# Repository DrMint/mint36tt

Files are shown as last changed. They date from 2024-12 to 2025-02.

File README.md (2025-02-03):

# Mint36tt (provisional name)

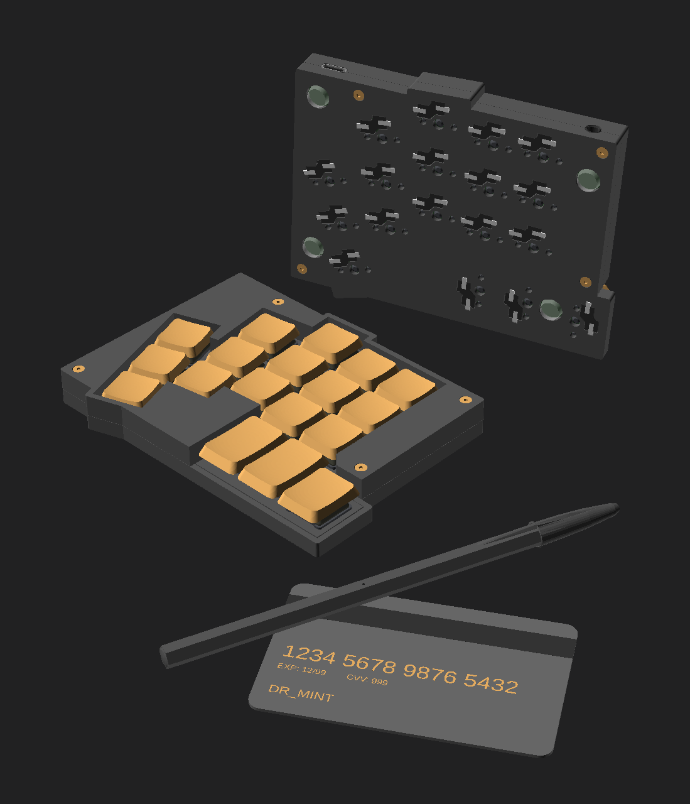
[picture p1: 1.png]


## Design goals

1. Ergonomic
   - Split
   - Reduced number of keys
   - Reduced key spacing
   - Splay
2. On-the-go

   - Low profile
   - Silent
   - Small footprint
   - key protection
   - Light
   - USB-C

3. Sourceable
   - Open source hardware
   - 3D printable (FDM)
   - Common components
   - Hot swappable board and switches
   - Reasonably cheap

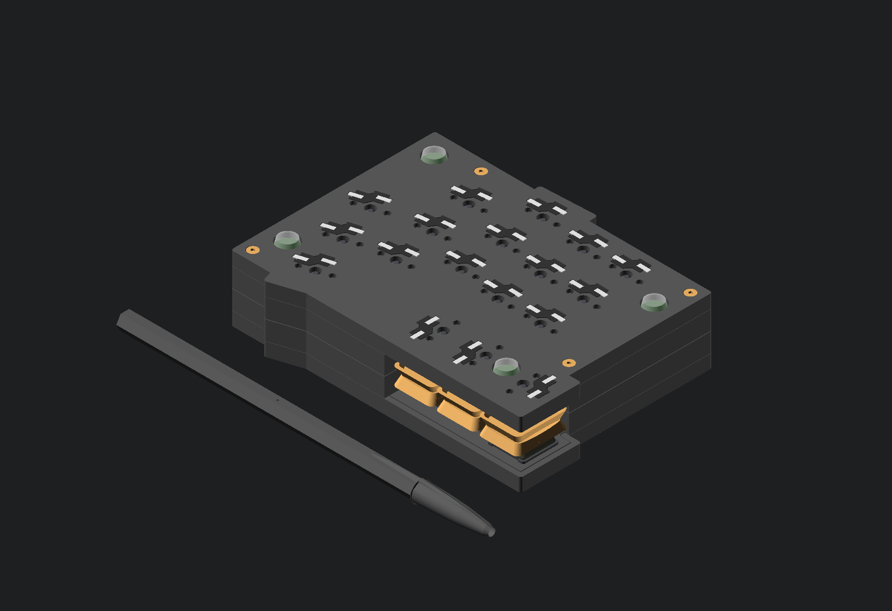
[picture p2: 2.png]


_The two halves combines together using magnets to transform into its own carry case. This prevent damage to the keys during transport and protect the keyboard from dust._

Physical sizes for one half:

**Width**: 118.5mm  
**Height**: 90.5mm  
**Thickness**: 14.8mm
**Weight**: 110g (wired version)

## Switches

Kailh Choc switches are the thinnest at 11mm (ref. https://www.reddit.com/r/MechanicalKeyboards/comments/165c11v/the_biggest_issue_with_lowprofile_switches_they/).

There are thinner switches such as the Kailh Notebook X (6.5mm) or the Cherry MX Ultra low-profile (3.5mm). But these are more expensive and don't have much variety.

Choosen switches: **[Kailh Choc Ambient Silent](https://lowprokb.ca/products/ambients-silent-choc-switches)**

## Key caps

Chocs standard keycaps are 16.5mm × 17.5mm. I decided to go with 16.5mm × 16.5mm CBX keycaps from Chosfox, which results in a 17.5mm spacing (a ~15% area reduction compared to MX's 19mm spacing).

It's possible to buy [15mm keycaps](https://3dkeycap.com/products/choc-colored-keycap-set) for a 16mm spacing (~30% area reduction). That would be the smallest possible spacing when paired with Chocs as 15mm is already the size of the switches.

It's also possible to reduce the gap beween keys. The standard is 1mm, but it could possibly be reduced to 0.5mm if the switches have little to no wobble and the tolerances on other parts are top notch.

Choosen caps: **[CFX caps](https://chosfox.com/collections/choc-keycaps)**

## Microcontroller

Choosen microcontroller: **[Seeed Studio XIAO RP2040](https://www.seeedstudio.com/XIAO-RP2040-v1-0-p-5026.html)** or **[Seeed Studio XIAO nRF52840](https://www.seeedstudio.com/Seeed-XIAO-BLE-nRF52840-p-5201.html)** for wireless.

## Shopping list

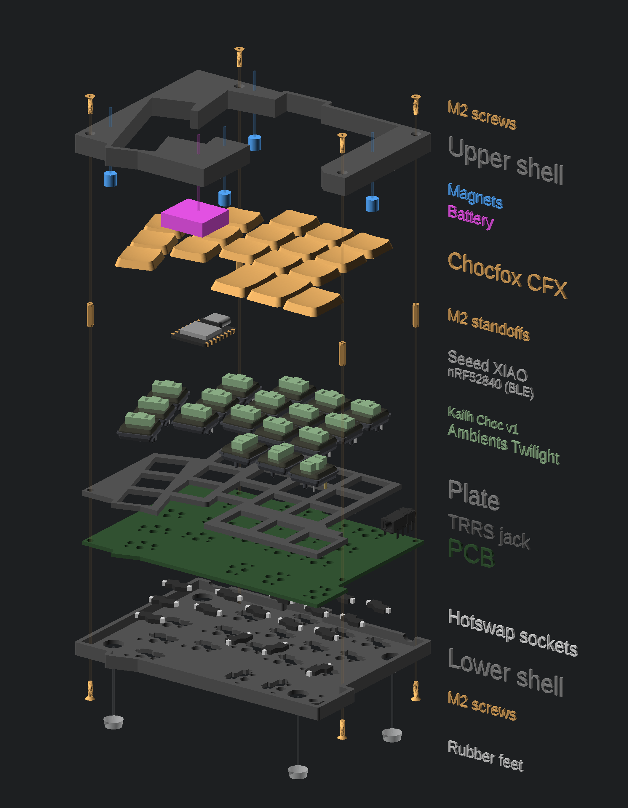
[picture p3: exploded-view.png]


### Common for either version

- Left and right PCBs
- 4 × 7 pin headers
- 36 × 1N4148W SOD123 diodes
- 36 × Chocfox CFX caps, including:
  - 30 × 1U Chocfox CFX caps
  - 2 × 1.25U Chocfox CFX caps
  - 4 × 1.5U Chocfox CFX caps
- 36 × Kailh Choc switches
- 36 × Kailh Choc Hot Swap Sockets
- 1 × USB-C cable

### Specific for the wireless version

- 2 × Seeed Studio XIAO nRF52840
- 2 × 601818 LiPo 3.7V 170mAh (18mm × 20mm × 6mm)
- 2 × MSK12C02 on/off slide switch

### Specific for the wired version

- 2 × Seeed Studio XIAO RP2040
- 1 × TRRS cable
- 2 × TRRS jacks PCB mount (MJ-4PP-9 or PJ320A)

### With the case (recommended):

- Left and right upper cases
- Left and right lower cases
- Left and right plates (optional)
- 8 × N52 neodymium magnet (cylinder-shaped, Ø 5mm × 5mm) (recommended)
- 20 × M2 countersunk screws (Ø 2mm × 5mm)
- 10 × M2 standoffs (Ø 2mm × 9mm)

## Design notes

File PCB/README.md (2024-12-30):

# Mint36tt

## Generate PCB file

```sh
npm i
npm start
```

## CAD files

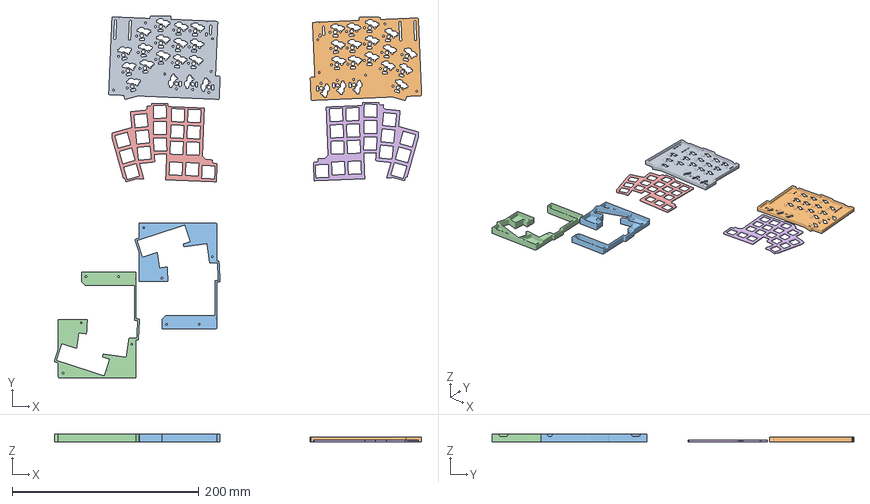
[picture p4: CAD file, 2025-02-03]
Case/mint36tt.3mf
393.8 x 388.0 x 8.90 mm
lower_shell_left.stl
lower_shell_right.stl
upper_shell_right.stl
upper_shell_left.stl
plate_right.stl
plate_left.stl

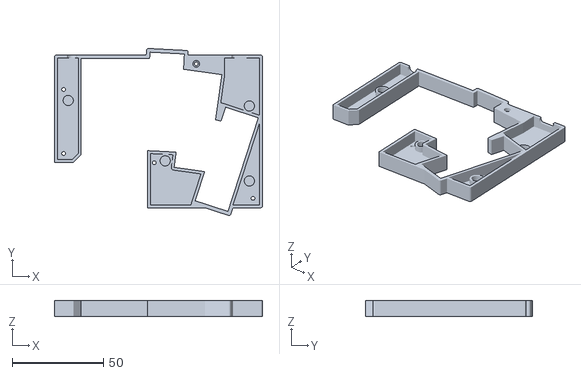
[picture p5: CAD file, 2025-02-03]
Case/STLs/Left/upper_shell_left.stl
113.7 x 91.3 x 8.90

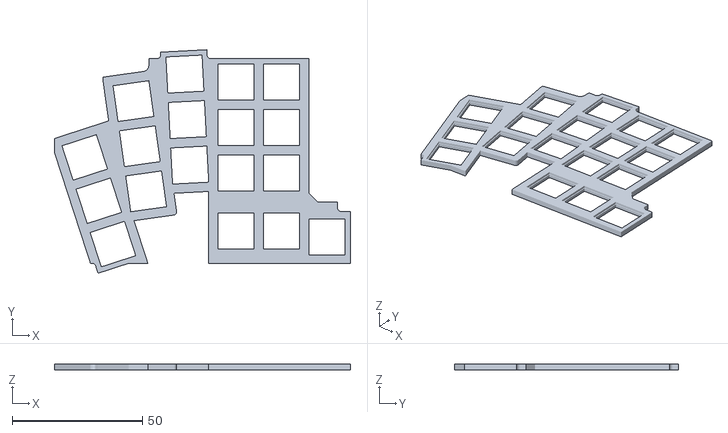
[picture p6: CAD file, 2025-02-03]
Case/STLs/Right/plate_right.stl
113.7 x 85.9 x 2.20

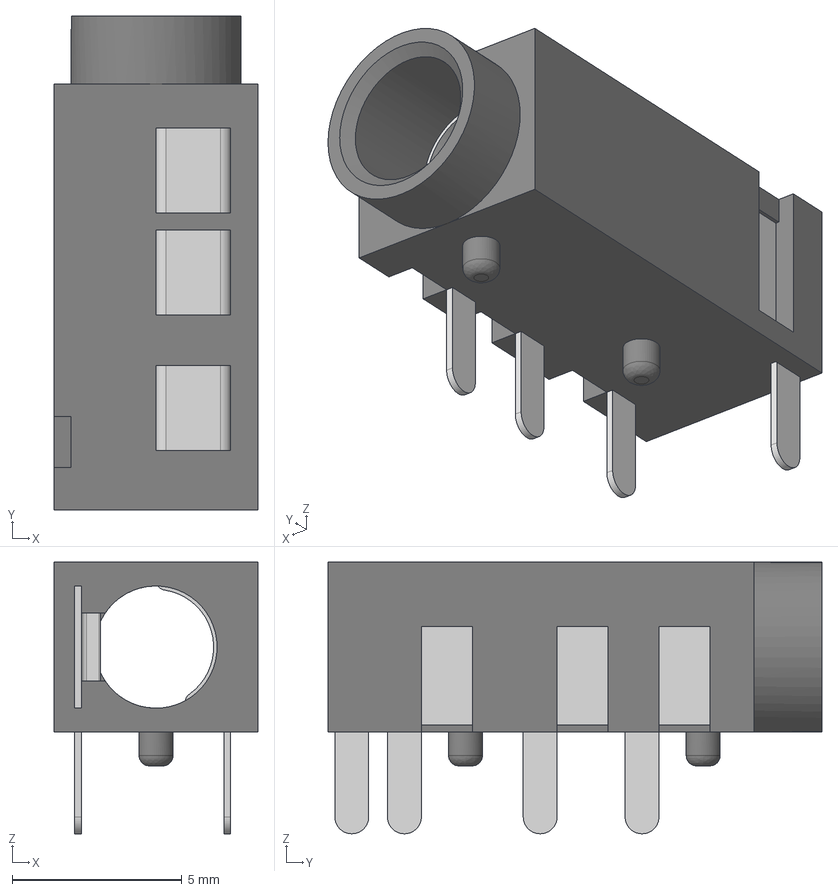
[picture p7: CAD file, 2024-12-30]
PCB/3d-models/PJ320A.step
6.00 x 14.6 x 8.00 mm

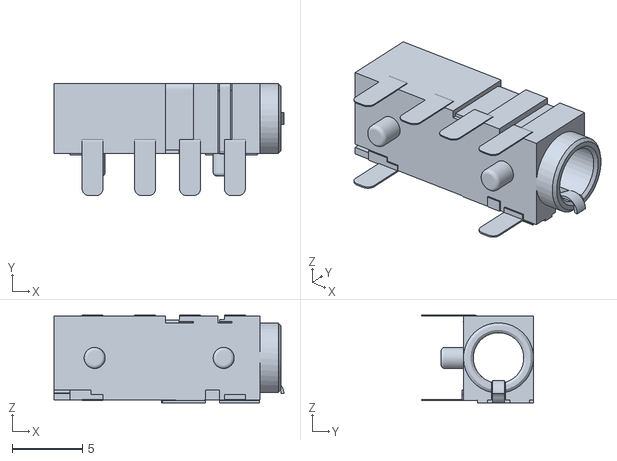
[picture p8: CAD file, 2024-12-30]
Case/components/ttrs-jack.stl
16.4 x 8.00 x 6.25

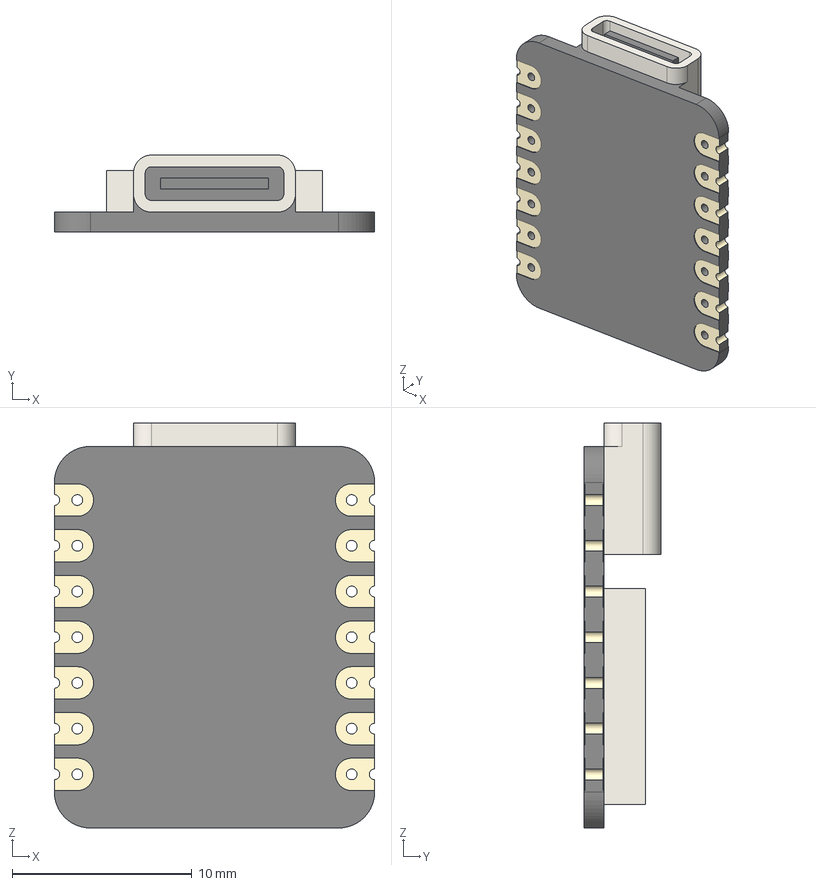
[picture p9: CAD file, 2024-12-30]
PCB/3d-models/XIAO-nRF52840.step
17.8 x 4.27 x 22.5 mm

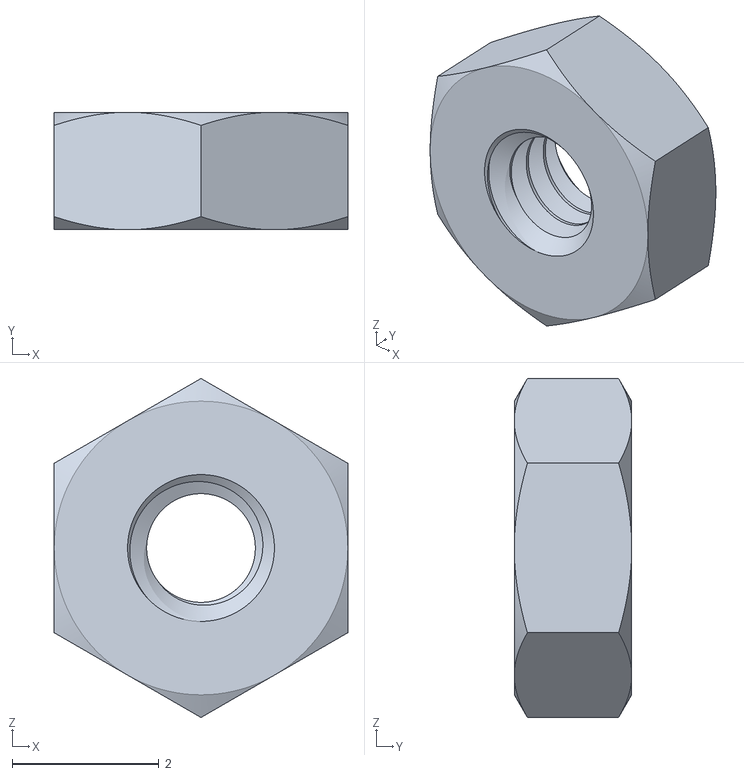
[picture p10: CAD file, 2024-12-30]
Case/components/m2-standoff.stl
4.00 x 1.60 x 4.62

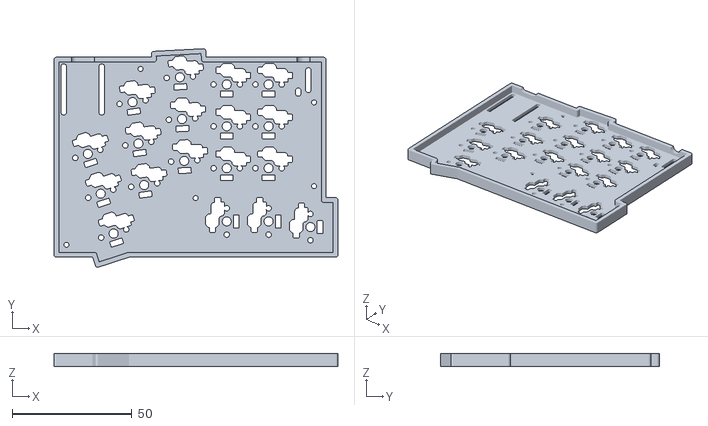
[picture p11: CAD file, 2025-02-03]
Case/STLs/Left/lower_shell_left.stl
118.7 x 91.3 x 5.60

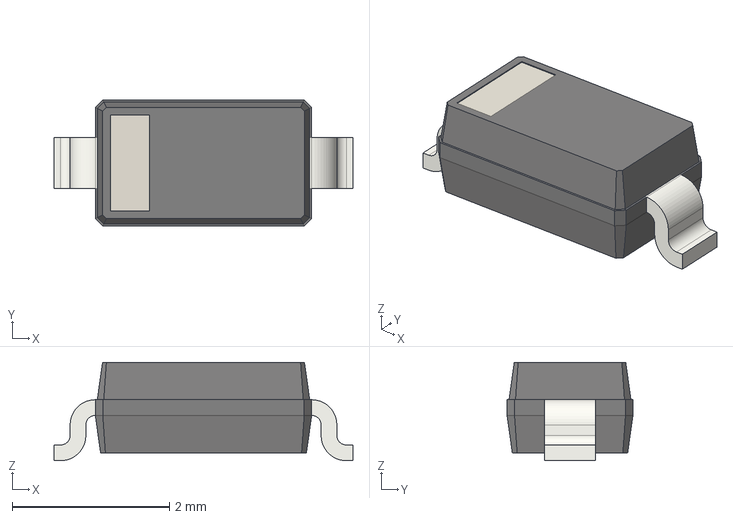
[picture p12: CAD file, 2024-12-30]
PCB/3d-models/SOD-123.step
3.80 x 1.60 x 1.25 mm

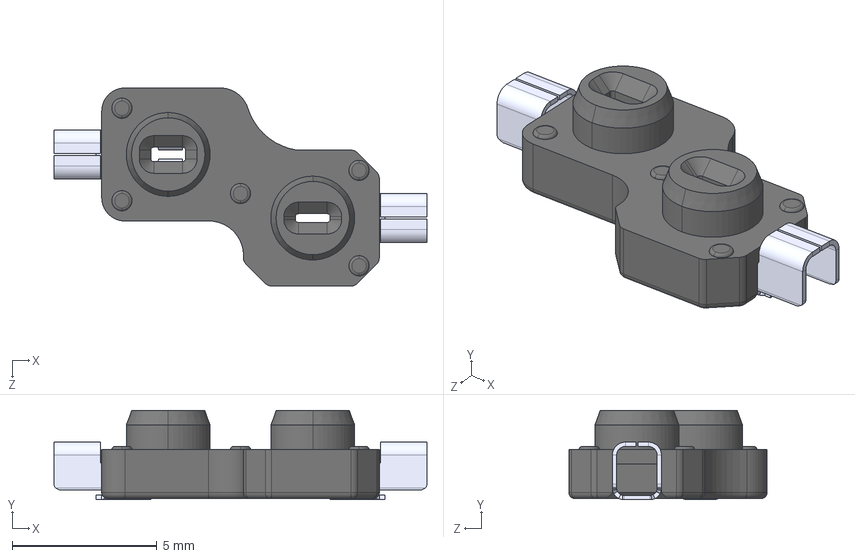
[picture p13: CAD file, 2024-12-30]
PCB/3d-models/PG1350-hotswap.step
12.9 x 3.09 x 6.85 mm
pin x 2
socket

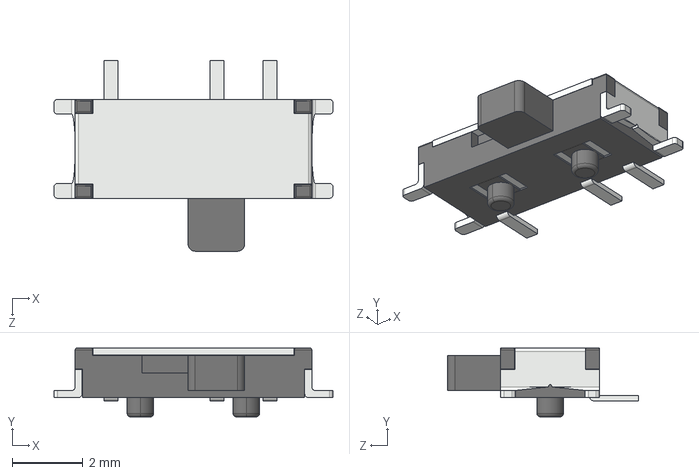
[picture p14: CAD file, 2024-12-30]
PCB/3d-models/MSK12C02.step
7.90 x 1.95 x 5.39 mm

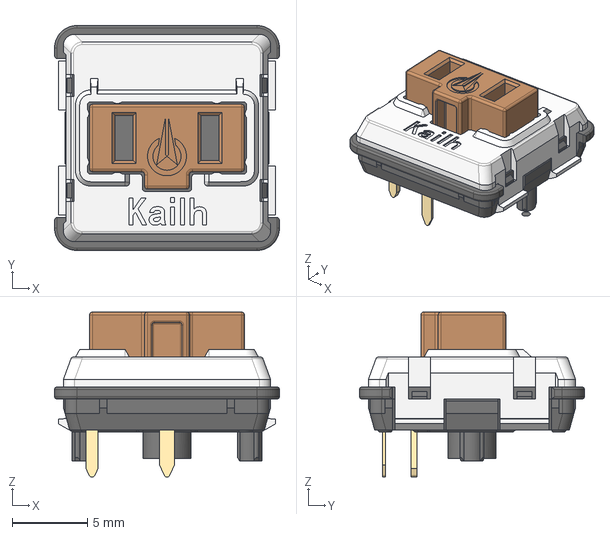
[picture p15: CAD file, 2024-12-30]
PCB/3d-models/PG1350-switch.step
15.0 x 15.0 x 11.0 mm

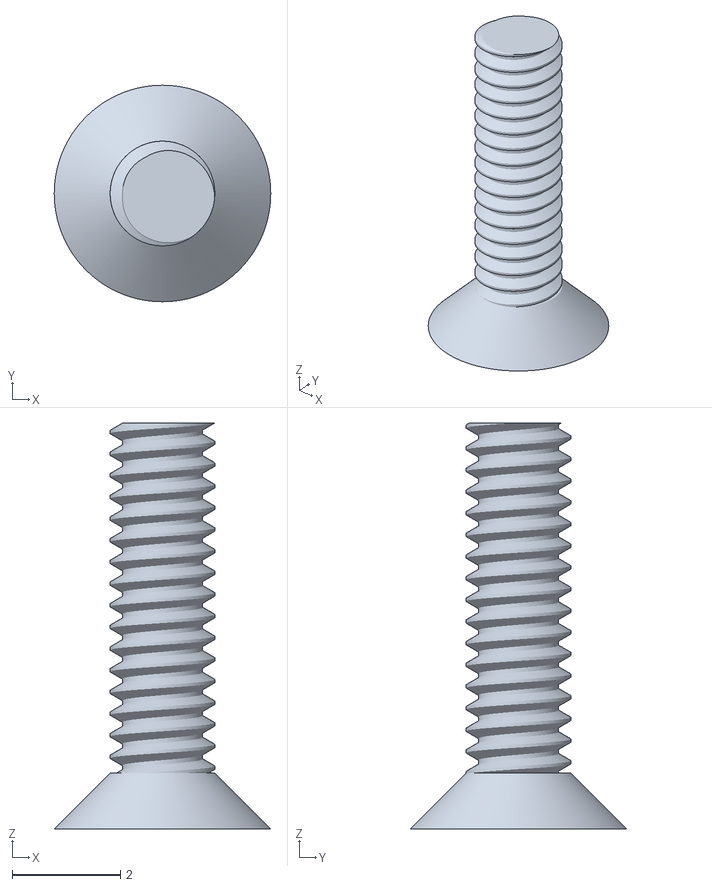
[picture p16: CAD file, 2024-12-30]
Case/components/m2-screw-6mm.stl
4.00 x 4.00 x 7.50

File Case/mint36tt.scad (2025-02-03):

include <./components/kailh-choc-v1.scad>
include <./components/cfx-caps.scad>

// include <./common.scad>

// Width: 117.5mm
// Height: 91mm
// Thickness: 14.7mm (14.0mm without the rubber feets)


/* [3D printing] */
kerf = 0.1;

/* [Keycaps & switches] */
Enable_switches = true;
Enable_caps = true;
Keycap_color = "#ffffffaa";
Thumb_cluster_color = "#eeeeee";

/* [Shell] */
Wall_thickness = 2.0;
Shell_size = [111.7, 81.575];
Shell_position = [-71.2, -53.675];
Shell_color = "#555555";

/* [Upper shell] */
Enable_upper_shell = true;
Upper_shell_thickness = 2.5;
Upper_shell_height = 8.9;
Enable_magnets = true;
Upper_shell_magnet_thickness = 0.5;
Magnet_height = 5.0;
Magnet_diameter = 5.0;

/* [Lower shell] */
Enable_lower_shell = true;
Lower_shell_thickness = 1.8;

/* [Plate] */
Enable_plate = true;
Plate_thumb_size = [116.7, 22.875];
Plate_thickness = 2.2;

/* [Screws] */
Enable_screws = true;
Screw_hole_radius = 1;
Screw_hole_distance = 1.5;
Countersink_height = 1.2;
Countersink_diameter = 3.5;
Screw_spacer_radius = 3.1/2;

/* [Microcontroller] */
Enable_microcontroller = true;
Micro_size = [17.8, 21, 1.26];
Micro_size_with_USB = 22.7;
Micro_position = [-67.6, 6.4, -1];

/* [Battery] */
Enable_battery = true;
Battery_size = [18, 20, 6];
Battery_position = [-20.1, -42.95];

/* [PCB] */
Enable_PCB = true;
PCB_thickness = 1.6;
Enable_sockets = true;
Enable_TTRS = true;
TTRS_position = [28.8, 12.5, -5.2];

/* [Debug] */
Debug_splay = 32.0; // [0:1:32]
Debug_text_distance = 70;
Debug_text_shift = 15;
Enable_debug_text = true;


module keys(withoutThumb=false, cutout=false, batteryCutout=false) {
    if (cutout) translate([-ku, ku]) capSize(16.8, 16.8) children();
    translate([0, ku]) capSize(16.8, 16.8) capColor(Keycap_color) children();
    translate([0, 0]) capSize(16.8, 16.8) capColor(Keycap_color) children();
    translate([0, -ku]) capSize(16.8, 16.8) capColor(Keycap_color) children();
    
    translate([ku, ku]) capSize(16.8, 16.8) capColor(Keycap_color) children();
    translate([ku, 0]) capSize(16.8, 16.8) capColor(Keycap_color) children();
    translate([ku, -ku]) capSize(16.8, 16.8) capColor(Keycap_color) children();
    
    rotate(3) translate([-18.5, 4]) {
        if (cutout) translate([ku, 0]) capSize(16.8, 16.8) children();
        translate([0, ku]) capSize(16.8, 16.8) capColor(Keycap_color) children();
        translate([0, 0]) capSize(16.8, 16.8) capColor(Keycap_color) children();
        translate([0, -ku]) capSize(16.8, 16.8) capColor(Keycap_color) children();
    }
    
    rotate(8) translate([-37.58, -2]) {
        if (cutout) translate([ku, ku]) capSize(16.8, 16.8) children();
        if (cutout) translate([ku, 0]) capSize(16.8, 16.8) children();
        if (batteryCutout) translate([1.25, ku * 2]) rotate(-8) capSize(16.8, 16.8) children();
        translate([0, ku]) capSize(16.8, 16.8) capColor(Keycap_color) children();
        translate([0, 0]) capSize(16.8, 16.8) capColor(Keycap_color) children();
        translate([0, -ku]) capSize(16.8, 16.8) capColor(Keycap_color) children();
    }
    
    rotate(18) translate([-58.79, -10.5]) {
        if (cutout) translate([ku, ku / 2]) rotate(-5) capSize(16.8, 16.8) children();
        if (cutout) translate([ku / 2, 0]) capSize(16.8, 16.8) children();
        if (batteryCutout) translate([0, -ku * 2]) capSize(16.8, 16.8) children();
        if (batteryCutout) translate([ku, ku]) capSize(16.8, 16.8) children();
        translate([0, ku]) capSize(16.8, 16.8) capColor(Keycap_color) children();
        translate([0, 0]) capSize(16.8, 16.8) capColor(Keycap_color) children();
        translate([0, -ku]) capSize(16.8, 16.8) capColor(Keycap_color) children();
    }
    
    if (!withoutThumb) rotate(0) translate([ku, -35.65 - gap]) {
        if (cutout) rotate(45) translate([5, 0]) capSize(16.8, 16.8) children();
        translate([ku, -5.475]) capSize(21.35, 16.8) rotate(90) capColor(Thumb_cluster_color) children();
        translate([0, -3.1]) capSize(26.1, 16.8) rotate(90) capColor(Thumb_cluster_color) children();
        translate([-ku, -3.1]) capSize(26.1, 16.8) rotate(90) capColor(Thumb_cluster_color) children();
    }
}

module screwPositions() {
    translate([36.5, 10]) children();
    translate([36.5, -25]) children();
    translate([-67, -49.5]) children();
    translate([-36, 24]) children();
    translate([-13, -30]) children();
}

module magnetPositions() {
    translate([34, 4]) children();
    translate([-19, -29]) children();
    translate([-65, 1]) children();
    translate([-65, -40]) children();
}

module rubberFeetPositions() {
    translate([26, -40]) children();
    translate([33.5, 13]) children();
    translate([-63.5, 20]) children();
    translate([-63.5, -40]) children();
}

half();
*translate([120, 0, 0]) half(flip=true);


/* [Hidden] */
zshift = $preview ? 0.01 : 0;
base_size = 16.5;
gap = 1.0;
ku = base_size + gap;
$fn = 64;

module condMirror(flip) {
    if (flip) {
        mirror([1, 0, 0]) children();
    } else {
        children();
    }
}

module condFlip(flip) {
    if (flip) {
        rotate(180) children();
    } else {
        children();
    }
}

module hotswap() {
    color("#333333") linear_extrude(1.8) {
        difference() {
            union() {
                translate([-2.05 + 1.5, 3.65 + 1.5]) offset(delta=1.5, chamfer=true) square([4.75 - 3, 4.65 - 3]);
                translate([2.7 + 1, 3.65 - 2.2 + 1]) offset(1) square([9.55 - 4.75 - 2, 4.65 - 2]);
                translate([5, 1.45]) square([2.7, 0.7]);
                translate([1.15, 2.05]) difference() {
                    square([2, 4]);
                    color("red") circle(1.6);
                } 

                translate([3.5, 6.9]) difference() {
                    translate([-2, -2]) square([2, 2]);
                    color("red") circle(0.8);
                }
            }
            translate([0, 5.9]) circle(0.5);
            translate([5, 5.9 - 2.2]) circle(0.5);
        }
    }
    
    color("#dddddd") linear_extrude(1.8) {    
        translate([7.5, 2.9]) square([2.0, 1.68]);
        translate([-4.05, 2.9 + 2.2]) square([2.0, 1.68]);
    }
}

module upperShellEmptySpaces() {
    offset(-1.6) difference() {
        translate(Shell_position) offset(1) square(Shell_size);
        keys(cutout=true, batteryCutout=true) offset(delta=1) cap_2d();
        translate([-9.4, -55]) square([55, 25.2]);
    }
}

module switches(flip) {
    translate([0, 0, -0.1 * Debug_splay]) {
        keys() rotate(180) condMirror(flip) kailthChocV1();
        if (Enable_debug_text) color("#90b48b") rotate([90, 0, 0]) {
            translate([Debug_text_distance, 4 + Debug_text_shift]) text("Kailh Choc v1", size=4);
            translate([Debug_text_distance, -4 + Debug_text_shift]) text("Ambients Twilight", size=5);
        }
    }
}

module caps() {
    translate([0, 0, Debug_splay * 2]) {
        keys() translate([0, 0, 2.5 + zshift]) cfxCap();
        if (Enable_debug_text) color(Thumb_cluster_color) rotate([90, 0, 0]) translate([Debug_text_distance, Debug_text_shift]) text("Chocfox CFX", size=7);
    }
}

module ioCutouts() {
    translate([Micro_position.x, Micro_position.y, 1.5]) translate([4.5, Micro_size.y + (Micro_size_with_USB - Micro_size.y), -1]) rotate([90]) linear_extrude(height = 7.4)  offset(r=1.6 + kerf * 2) square([6, 0.3]);
    
    translate([TTRS_position.x - 1.32, TTRS_position.y, 2.2]) translate([4.5, -1.5 + Micro_size.y + (Micro_size_with_USB - Micro_size.y), -1.9]) rotate([90]) linear_extrude(height = 7.4)  offset(r=2.5 + kerf * 2) square([0.1, 0.1]);
}
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

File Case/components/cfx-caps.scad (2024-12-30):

/home/deck/custom-keyboard/openSCAD/caps/cfx-caps.scad

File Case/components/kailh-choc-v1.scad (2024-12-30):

/home/deck/custom-keyboard/openSCAD/switches/kailh-choc-v1.scad

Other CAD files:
Case/STLs/Left/plate_left.stl
Case/STLs/Right/upper_shell_right.stl
Case/STLs/Right/lower_shell_right.stl

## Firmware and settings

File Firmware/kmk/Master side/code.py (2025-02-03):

import board
from kmk.kmk_keyboard import KMKKeyboard
from kmk.keys import KC
from kmk.scanners import DiodeOrientation
from kmk.modules.split import Split, SplitSide, SplitType
from storage import getmount
import neopixel

print("Starting Mint36tt")

side = SplitSide.LEFT if str(getmount('/').label)[-1] == "L" else SplitSide.RIGHT

print("Board pins:", dir(board))
print("Side:", "RIGHT" if side == SplitSide.RIGHT else "LEFT")

keyboard = KMKKeyboard()
keyboard.col_pins = (board.D0, board.D1, board.D2, board.D3, board.D4)
keyboard.row_pins = (board.D8, board.D9, board.D10, board.D5)
keyboard.diode_orientation = DiodeOrientation.COL2ROW

# [Combos]

from kmk.modules.combos import Combos, Chord
combos = Combos()
keyboard.modules.append(combos)

combos.combos = [
    # Chord((KC.BSPC, KC.SPC), KC.ENTER, timeout=50),
]

# [Holdtap]

from kmk.modules.holdtap import HoldTap
holdtap = HoldTap()
keyboard.modules.append(holdtap)

LCTL = KC.HT(KC.A, KC.LCTRL, prefer_hold=False)
LGUI = KC.HT(KC.S, KC.LGUI, prefer_hold=False)
LALT = KC.HT(KC.D, KC.LALT, prefer_hold=False)
LSFT = KC.HT(KC.F, KC.LSFT, prefer_hold=False)
 
RSFT = KC.HT(KC.J, KC.RSFT, prefer_hold=False)
RALT = KC.HT(KC.K, KC.RALT, prefer_hold=False)
RGUI = KC.HT(KC.L, KC.RGUI, prefer_hold=False)
RCTL = KC.HT(KC.SCLN, KC.RCTRL, prefer_hold=False)

# [Layers]

from kmk.modules.layers import Layers
keyboard.modules.append(Layers())

BSPACE = KC.LT(1, KC.BSPACE)
SPACE = KC.LT(2, KC.SPACE)

# ------------------------------------------------------------------------------

keymap = [
    
    # (0) Alpha layer
    [
        KC.Q,     KC.W,     KC.E,      KC.R,      KC.T,                                      KC.Y,     KC.U,       KC.I,     KC.O,      KC.P,

        LCTL,     LGUI,     LALT,      LSFT,      KC.G,                                      KC.H,     RSFT,       RALT,     RGUI,      RCTL,

        KC.Z,     KC.X,     KC.C,      KC.V,      KC.B,                                      KC.N,     KC.M,     KC.COMM,   KC.DOT,   KC.SLSH,

                                      KC.ESC,    BSPACE,   KC.TAB,            KC.ENTER,      SPACE,   KC.DEL
    ],


    # (1) Num layer
    [
        KC.NO,    KC.NO,    KC.NO,    KC.NO,      KC.NO,                                    KC.NO,   KC.KP_7,   KC.KP_8,   KC.KP_9,   KC.KP_MINUS,

        KC.NO,    KC.NO,    KC.NO,    KC.NO,      KC.NO,                           KC.KP_ASTERISK,   KC.KP_4,   KC.KP_5,   KC.KP_6,   KC.KP_PLUS,

        KC.NO,    KC.NO,    KC.NO,    KC.NO,      KC.NO,                              KC.KP_SLASH,   KC.KP_1,   KC.KP_2,   KC.KP_3,   KC.KP_ENTER,

                                      KC.NO,      KC.NO,    KC.NO,            KC.SPACE,   KC.KP_0,  KC.KP_DOT
    ],

    # (2) Nav layer
    [
        KC.NO,    KC.NO,    KC.UP,    KC.NO,      KC.NO,                                    KC.NO,     KC.NO,     KC.NO,     KC.NO,     KC.NO,

        KC.NO,   KC.LEFT,  KC.DOWN,  KC.RIGHT,    KC.NO,                                    KC.NO,     KC.NO,     KC.NO,     KC.NO,     KC.NO,

        KC.NO,    KC.NO,    KC.NO,    KC.NO,      KC.NO,                                    KC.NO,     KC.NO,     KC.NO,     KC.NO,     KC.NO,

                                      KC.NO,      KC.NO,    KC.NO,              KC.NO,      KC.NO,     KC.NO
    ],
]



# ------------------------------------------------------------------------------

# [Split]

split = Split(
    split_side=side,
    split_type=SplitType.UART,
    data_pin=board.TX,
    data_pin2=board.RX,
    use_pio=True
)
keyboard.modules.append(split)

indexes = [
     4,  3,  2,  1,  0,             9,  8,  7,  6,  5,
    14, 13, 12, 11, 10,            19, 18, 17, 16, 15,
    24, 23, 22, 21, 20,            29, 28, 27, 26, 25,
                32, 31, 30,    35, 34, 33
]

indexesLut = [
    0,
    1,
    2,
    3,
    4,
    5,
    6,
    7,
    8,
    9,
    10,
    11,
    12,
    13,
    14,
    15,
    16,
    17,
    18,
    19,
    20,
    21,
    22,
    23,
    24,
    25,
    26,
    27,
    28,
    29,
    30,
    31,
    32,
    None,
    None,
    None,
    None,
    33,
    34,
    35,
]

keyboard.keymap = [[layer[indexes[index]] if index != None else KC.TRNS for index in indexesLut] for layer in keymap]

led = neopixel.NeoPixel(board.NEOPIXEL, 1)
led.brightness = 0.05
led[0] = (255, 0, 0)

if __name__ == "__main__":
    keyboard.go()
